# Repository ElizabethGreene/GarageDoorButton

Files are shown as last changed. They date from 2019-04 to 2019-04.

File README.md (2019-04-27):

# GarageDoorButton
A tiny webserver for the ESP8266 to control a garage door opener

This was written to work with the ESP-01 wireless module and a relay board.
The ebay item is "ESP8266 ESP-01S + 5V WiFi Relay Module Smart Home Remote Control Unlock Set"

https://www.ebay.com/itm/ESP8266-ESP-01S-5V-WiFi-Relay-Module-Smart-Home-Remote-Control-Unlock-Set/382656556255

"Configuring the IDE and Breadboard.docx" contains additional dev documentation.

"ESP8266 Relay Board Case.F3d" contains a Fusion 360 model for a 3D printable two-part case

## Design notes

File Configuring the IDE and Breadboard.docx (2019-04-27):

Step zero is to get the Arduino IDE setup to work with the ESP8266.

  1.1 For Windows, get the IDE from the Windows Store.
  1.2 Under the preferences menu, add in the following additional Boards Manager url.

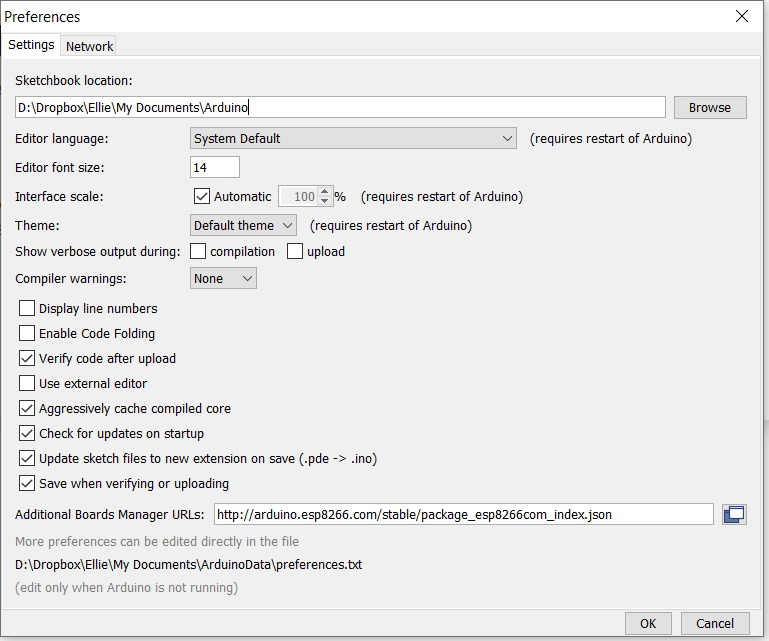
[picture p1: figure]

  1.3 Launch the Arduino Board Manager

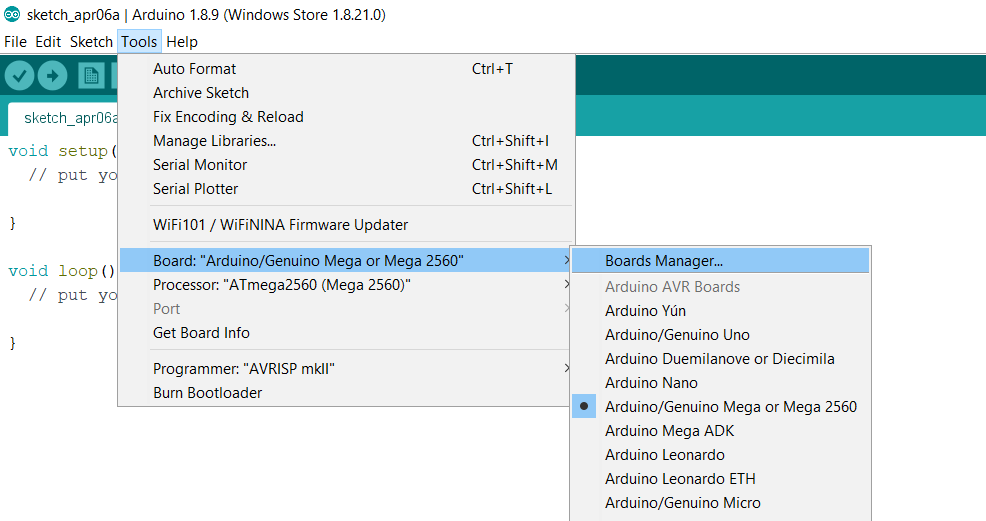
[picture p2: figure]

  1.4 Wait for the Board manager to pull the list from the internet and search for ESP8266.

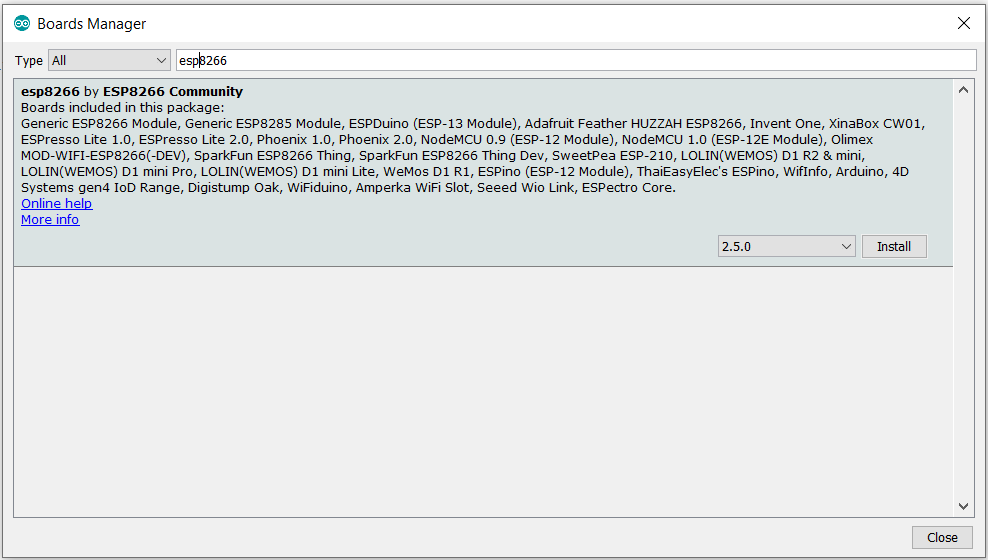
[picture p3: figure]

  1.5 Click Install.
  1.6 When the module shows installed, click close

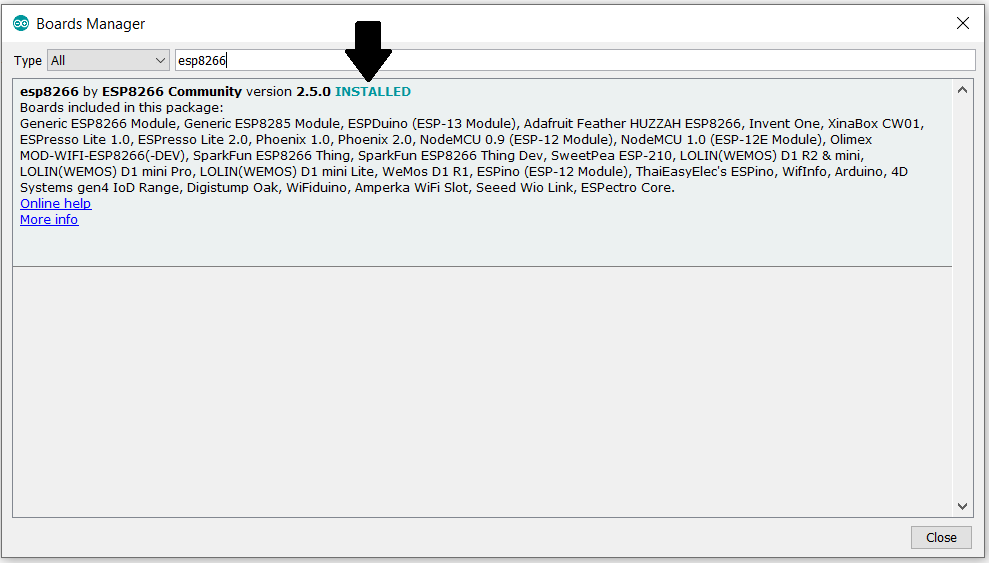
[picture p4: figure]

  1.7 Finally, select the Generic ESP8266 module from the Tools >> Board Menu.

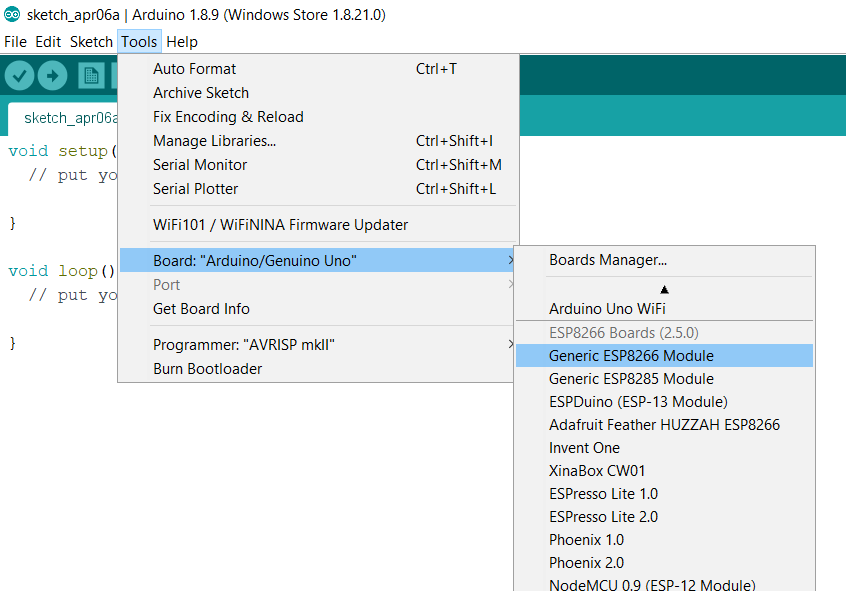
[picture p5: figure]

1.0 Connecting to the ESP8266
  1.1 My Microcontroller is an ESP-01 board, and there are some things you need to know.
    1.1.1 It requires a 3.3v supply. A 5v supply cooks it.
    1.1.2 It draws a fair amount of current for a 3.3v device.
    1.1.3 It requires 3.3v levels on the serial interface
  1.2 Physical wiring to the ESP8266
    1.2.1 I’m using male-to-female jumper wires to connect the ESP to my breadboard.

Red-3.3v supply on Breadboard
Black-Ground on breadboard
Blue-RST
Grey-TX
Green-RX
Purple-CH_PD – VCC
GPIO2 not connected.

Yellow - GPIO0 (leave disconnected)

  1.3 For the 3.3v serial connection I’m using an Adafruit FTDI Friend
    1.3.1 Look at the back of the FTDI friend. Confirm that it is configured for 3.3v output.
    1.3.2 USB – To my PC RX to the TX wire(Grey) of the ESP8266 board TX to the RX wire(Green) of the ESP8266 board GND to the common ground on the breadboard VCC NOT CONNECTED – This outputs 5v by default, and will cook the ESP8266
  1.4 Find the correct serial port
    1.4.1 Launch device manger with the FTDI friend plugged in to the USB connection.
    1.4.2 Expand the ports section, note the available ports.
    1.4.3 If you have only one, that’s your serial port. Note the COM#. Mine is COM3
    1.4.4 If you have multiple serial ports listed, Unplug in the FTDI friend and then plug it back in. The port that disappears and reappears is the FTDI friend.
  1.5 Launch the Serial Monitor in the Arduino IDE
    1.5.1 Launch the Arduino IDE
    1.5.2 Select the COM port you found earlier under the Tools > Ports men

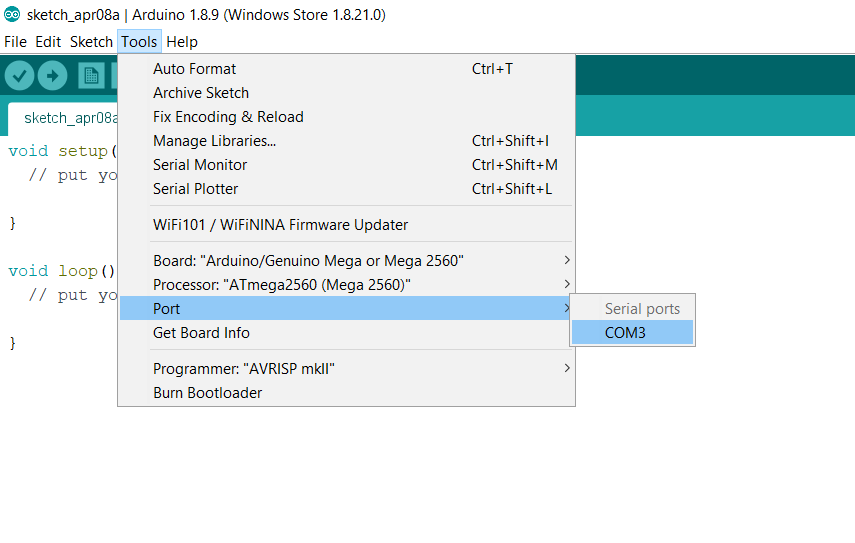
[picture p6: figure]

    1.5.3 Launch the serial monitor under Tools > Serial Monitor
    1.5.4 Select 115200 as the baud rate in the lower right of the Serial Monitor
    1.5.5 Select “Both NL & CR” as the end-of line in the lower right of the Serial Monitor
    1.5.6 Double-check your wiring, and turn on the breadboard 3.3v power supply with any luck your Serial monitor will display this

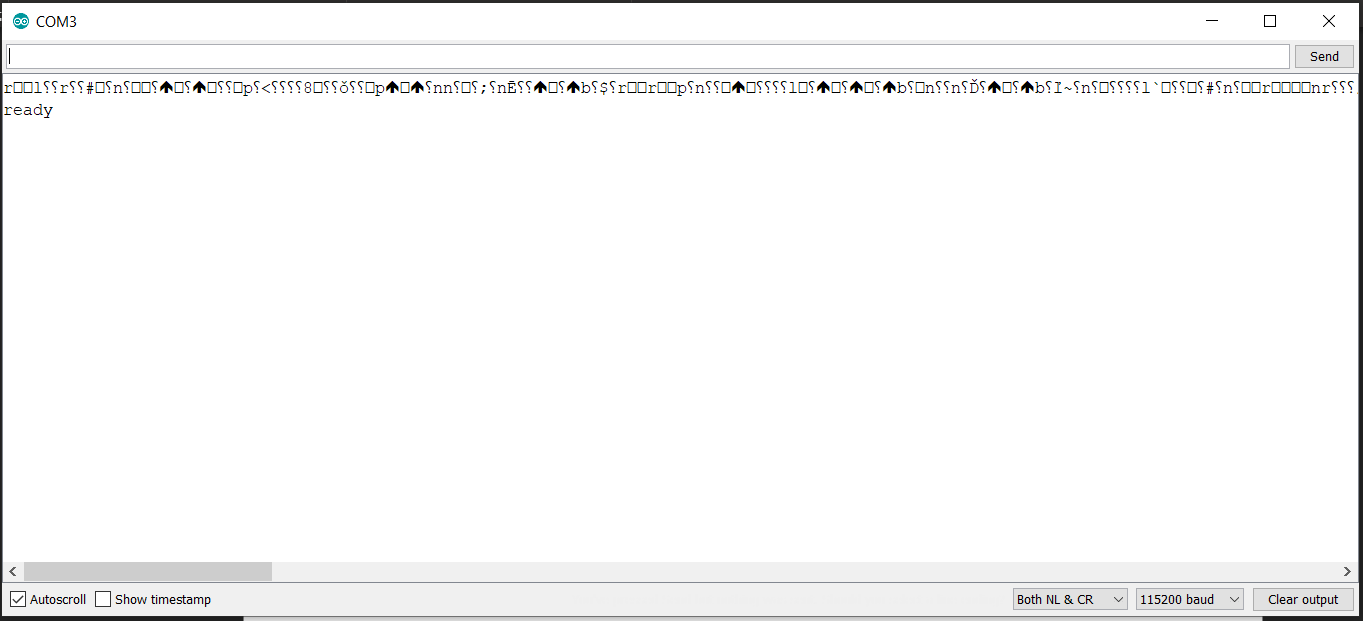
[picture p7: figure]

    1.5.7 Optional, Test your esp8266 using the stock AT commands. (This assumes that your ESP8266 is running the stock firmware.)
      1.5.7.1 In the serial Monitor, type AT and press enter. This should reply with OK.

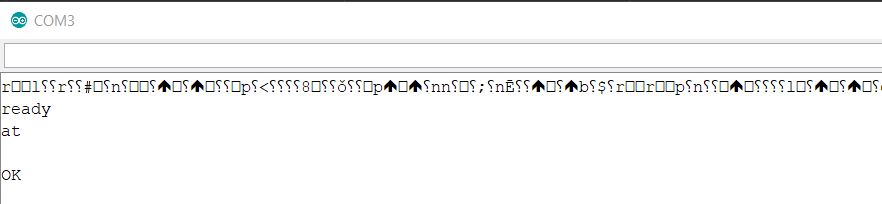
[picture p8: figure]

      1.5.7.2 At this prompt you can enter AT commands from the default ESP8266 command set listed here https://www.espressif.com/sites/default/files/documentation/4a-esp8266_at_instruction_set_en.pdf.)
      1.5.7.3 Type AT+GMR and press enter to see the current firmware version
      1.5.7.4 Type AT+CWLAP to list the available access points If this returns an error, use AT+CWMODE=1 to set it into Wifi Client Mode and try again.
      1.5.7.5 If you want to use the ESP8266 as wireless interface for an Arduino, stop here. You’ve confirmed that the board works and accepts serial connections. I’m going to be replacing the default firmware with an Arduino sketch, so I must keep going.
2.0 Place the ESP8266 board into programming mode and upload a sketch
  2.1 Power off the breadboard.
  2.2 Connect the GPIO0 to Ground to place the device in programming mode
  2.3 Get the Blink.ino example sketch from https://github.com/esp8266/Arduino/blob/master/libraries/esp8266/examples/Blink/Blink.ino
  2.4 Open or Paste the sketch into the Arduino IDE and save it.
  2.5 Confirm that the generic ESP8266 is selected under the Tools > Board Menu
  2.6 Power on the breadboard
  2.7 Use the Arrow button on the tool to compile and upload the sketch

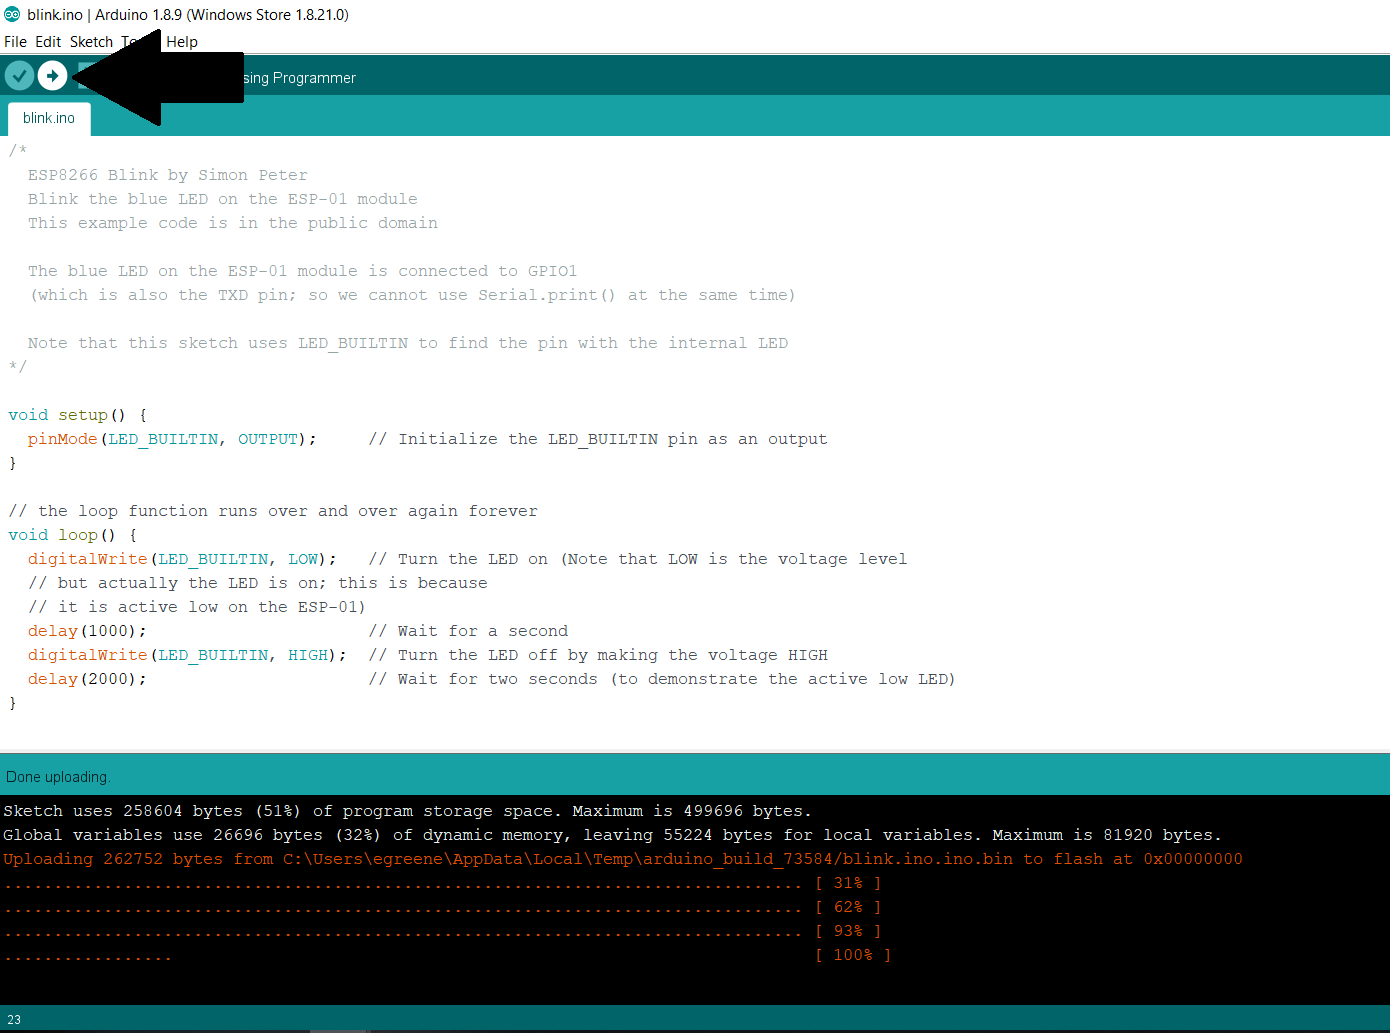
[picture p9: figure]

  2.8 When the upload completes, power off the breadboard.
  2.9 Connect GPIO2 to a LED with a current limiting resistor.
  2.10 Connect the other end of the LED to ground.
  2.11 Unplug the GPIO0 (Yellow) pin from ground to exit programming mode.
  2.12 Power on the breadboard. The LED you connected to pin 2 should blink.
  2.13 Revel in your god-like powers.
3.0 Figure out how to trigger the relay on your relay board. If you’ve bought well documented parts, good on you. Have a look at the data sheet and figure out how to trigger your relay and skip onto the next step. I didn’t do that, so I have to be clever.  Looking at my board I see that GPIO0 is connected to the input of an optoisolator. There is no visible connection to GPIO2, so I choose to believe that GPIO0 is the input I need. That’s half the battle. I also need to figure out what voltage the board operates at, i.e. what does it need for VCC and does it have an onboard voltage regulator.  Looking at the board I looked up several components and hit the jackpot with the LM1117-3.3. This is a low dropout 3.3 volt voltage regulator. I connected the relay board to my power supply with the ESP8266 not installed. Turning on the power supply I fed it 3.3 volts. I checked the voltage between ground and VCC pins for where the esp8266 would be installed. The output was 2.5 volts. This makes sense. The voltage regulator has a minimum voltage drop, so the 3.3v input wasn’t enough. I turned the input power up to 5V and measured 3.32v on where the ESP8266 should be. Yeah! Last but not least I plugged a 330 ohm resistor into the holes for VCC and GPIO0. That clicked the relay on as expected.  The final verdict: It appears to work with a 5 volt supply and toggles the relay with GPIO0.

Update: In debugging I found that LOW = on, HIGH=off. I don’t understand why, but I’m going with it.

4.0 Write the code. For me the minimum viable product objective is to connect to the WiFi and display a button that triggers the relay for 5 seconds.  Read the important note in the next section before pushing code to the microcontroller.
5.0 Publishing the code to the Esp8266
  5.1 NOTE! Read this so you don’t fry your chip! Entering programming mode requires grounding GPIO0. Using GPIO as an output while it is connected to ground will exceed current limits on the GPIO and can and will fry it. It did not damage my board, but it did prevent me from programming it until I figured this out.  To safely program the esp8266 power off the board, ground GPIO0, power on the board, remove GPIO0 from ground, and then program the board.
  5.2 Follow the procedure above to place the board into programming mode and push the compiled code to the esp8266 using the Arduino IDE.
6.0 Ideas for future improvement
  6.1 SSL support
  6.2 One-wire serial display on gpio2 to show current IP address
  6.3 A second button that toggles on/off
    6.3.1 With a thing that forces it off after ~25 seconds.
  6.4 Blink out the ip address on a LED

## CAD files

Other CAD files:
ESP8266 Relay Board Case .f3d

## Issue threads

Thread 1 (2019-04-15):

Wifi does not automatically reconnect if connectivity is lost

ElizabethGreene, 2019-04-15:
REPRO STEPS:
Boot Esp8266, connect to wifi, and confirm proper operation
Reboot AP
Connectivity is lost.

ElizabethGreene, 2019-04-25:
Got a repro leaving device and up on serial monitor overnight.  Device appears to be resetting for software watchdog.

```
........
Connected to TheGarage
IP address: 192.168.1.78
MDNS responder started
HTTP server started

 ets Jan  8 2013,rst cause:4, boot mode:(3,6)

wdt reset
load 0x4010f000, len 1384, room 16
tail 8
chksum 0x2d
csum 0x2d
v951aeffa
~ld

```

ElizabethGreene, 2019-04-27:
This was found to be a memory leak caused by a too tight main loop.  Fixed in 6d3af9b.

Closed 2019-04-27.

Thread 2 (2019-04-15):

Power-Cycling the Microcontroller+Relay Module opens the Garage door.

ElizabethGreene, 2019-04-15:
Unplugging the power brick causes the garage door to open.

ElizabethGreene, 2019-04-25:
Fixed by https://github.com/ElizabethGreene/GarageDoorButton/issues/7

ElizabethGreene, 2019-04-27:
Fixed in 6d3af9b.

Closed 2019-04-27.

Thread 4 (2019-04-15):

Remove need for external power supply

ElizabethGreene, 2019-04-15:
The two wires from the garage door opener provides 3.something volts DC.  If this could be used to power the kit then we wouldn't need an external power supply.  This is complicated by the fact that the voltage goes to zero when the button is pushed or the relay closes

Something like:
>>Input >> Protection >> Boost converter >> capacitors or rechargeable battery that can power the unit for some amount of time  >> power input.

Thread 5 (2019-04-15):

Electronics flop around in 3D-Printed Enclosure.

ElizabethGreene, 2019-04-15:
Redesign case with deeper recesses for the wall mounting screws and a snap-fit boss to hold the electronics in place.

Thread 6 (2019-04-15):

Release project under Open Source License

ElizabethGreene, 2019-04-15:
Project is currently of an unknown license.  Fix it.

60% of the source is verbatim from the sample code, and I don't know how to attribute that and still open source it.

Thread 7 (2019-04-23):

Relay board is wired as N/C instead of N/O.  That's not right.

ElizabethGreene, 2019-04-23:

ElizabethGreene, 2019-04-25:
Found problem.  LOW turns relay On, High turns relay OFF.

Intuitively that doesn't make a lot of sense, but changing it fixed it.  Also added explicit write to setup() to put into known state.

ElizabethGreene, 2019-04-27:
Fixed in 6d3af9b.

Closed 2019-04-27.

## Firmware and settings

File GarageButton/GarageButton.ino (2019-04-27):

// GarageButton.ino - Elizabeth Greene 2019
// Based on samplecode from https://github.com/esp8266/Arduino/blob/master/libraries/ESP8266WebServer/examples/HelloServer/HelloServer.ino

#include <ESP8266WiFi.h>
#include <WiFiClient.h>
#include <ESP8266WebServer.h>
#include <ESP8266mDNS.h>

#ifndef STASSID
#define STASSID "wifiSSID"
#define STAPSK  "wifiPassword"
#endif

#define GPIORELAY 0

const char* ssid = STASSID;
const char* password = STAPSK;

ESP8266WebServer server(80);

void handleRoot() {
  digitalWrite(LED_BUILTIN, 1);
  server.send(200, "text/html","<!DOCTYPE html><html><head><title>Garage Door Button</title><style> div { display: block; text-align: center; margin: auto;}  .block { display: block; width: 100%; height: 30%; border: none; background-color: #4CAF50; padding: 56px 28px; font-size: 32px; cursor: pointer; text-align: center; }</style></head><body><div><form action=\"\\push\" method=\"post\"><input type=\"submit\" class=\"block\" value=\"Push it\"/></form></div></body></html>");
}

void handlePush() {
  server.send(200, "text/html", "<!DOCTYPE html><html> <head>    <title>Garage Door Button</title>    <style> div { display: block; text-align: center; margin: auto;}    .block {  display: block;  width: 100%;  height: 30%;  border: none;  background-color: #FFFF00;  padding: 56px 28px;  font-size: 32px;  cursor: pointer;  text-align: center;}</style><meta http-equiv=\"refresh\" content=\"5; url=\\\" />  </head>  <body>    <div class=\"block\">Button has been pushed!</div></body></html>");
  digitalWrite(GPIORELAY, 0);
  delay(2000);                      // Wait for a second
  digitalWrite(GPIORELAY, 1);
}

void handleNotFound() {
  digitalWrite(LED_BUILTIN, 1);
  String message = "File Not Found\n\n";
  message += "URI: ";
  message += server.uri();
  message += "\nMethod: ";
  message += (server.method() == HTTP_GET) ? "GET" : "POST";
  message += "\nArguments: ";
  message += server.args();
  message += "\n";
  for (uint8_t i = 0; i < server.args(); i++) {
    message += " " + server.argName(i) + ": " + server.arg(i) + "\n";
  }
  server.send(404, "text/plain", message);
  digitalWrite(LED_BUILTIN, 0);
}

void setup(void) {
  pinMode(GPIORELAY, OUTPUT);   // Initialize the GPIO as the output pin for the relay
  pinMode(LED_BUILTIN, OUTPUT); // Initialize the built-in LED as an output

  digitalWrite(LED_BUILTIN, 0);
  digitalWrite(GPIORELAY,1);
  Serial.begin(115200);
  WiFi.mode(WIFI_STA);
  WiFi.begin(ssid, password);
  Serial.println("");

  // Wait for connection
  while (WiFi.status() != WL_CONNECTED) {
    delay(500);
    Serial.print(".");
  }
  Serial.println("");
  Serial.print("Connected to ");
  Serial.println(ssid);
  Serial.print("IP address: ");
  Serial.println(WiFi.localIP());

  if (MDNS.begin("esp8266")) {
    Serial.println("MDNS responder started");
  }

  server.on("/", handleRoot);

  server.on("/push", []() {
    // server.send(200, "text/plain", "this works as well");
    handlePush();
  });

  server.onNotFound(handleNotFound);

  server.begin();
  Serial.println("HTTP server started");
}

void loop(void) {
  server.handleClient();
  MDNS.update();
  delay(1000);
  //Uncomment this to output the free heap size to serial every loop.
  //Use it to find memory leaks.
  Serial.println(ESP.getFreeHeap(),DEC);
}

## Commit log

2019-04-15 Adding supporting information for project
    [ESP8266 Relay Board Case .f3d]
2019-04-27 First Major Bugfix
    * Fixed Inverted Relay
    - This fixed the Door-open-on-power-up bug
    * Fixed Hang after extended operation
    * Made button larger and added post-click redirect back to main page
    [GarageButton.ino]
